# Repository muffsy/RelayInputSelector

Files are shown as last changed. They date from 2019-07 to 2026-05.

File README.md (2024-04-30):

# Muffsy Relay Input Selector 4

This open source (BSD license) project contains Arduino Code, Autodesk Eagle PCB project files and gerbers that can be sent directly to any PCB manufacturer for production.

- https://www.muffsy.com/muffsy-relay-input-selector-4.html
- https://www.tindie.com/products/skrodahl/muffsy-relay-input-selector-kit/

The Muffsy Relay Input Selector is a simple, reliable, high quality, DIY stereo input selector that's controlled by an ESP-32 and is slightly larger than a Post-IT note. 

The Input Selector has four inputs, one output, a mute circuit and the option of controlling a solid state relay. It's controlled with a rotary encoder and an IR remote. 

As the heart of the Input Selector is an ESP32, with all pins broken out on the board, the possibilities are virtually limitles. The example code is written in Arduino, the native SDK could of course be used instead.

This kit is meant to be paired with a preamplifier circuit, such as the Muffsy BSTRD Class-A Tube Preamp, Pass Labs B1 and many others.

**This project**, including the schematic and board layout, **is open source**. It's licensed under the very permissive BSD 3-Clause "New" or "Revised" License.

**Update 2023-07-30:**
The software now works without modifications of Arduino libraries.

**Update 2023-09-16:**
Much improved code, with user configurable values. In particular for the IR remote codes and rotary encoder direction.

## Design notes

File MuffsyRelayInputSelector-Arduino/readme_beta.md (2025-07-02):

# Muffsy Relay Input Selector - Enhanced Version (Beta)

🎵 **Version 2.0.0** - Now with WiFi control, web interface, and OTA updates!

## 🆕 What's New in Version 2.0

This enhanced version of the Muffsy Relay Input Selector adds modern connectivity features while maintaining all the original functionality you know and love.

### ✨ New Features

- **📱 WiFi Control** - Control your input selector from your phone, tablet, or computer
- **🌐 Web Interface** - Clean, responsive web interface for easy control
- **🔄 Over-The-Air Updates** - Update firmware wirelessly without cables
- **💻 Web Console** - View device logs and status remotely
- **🔧 Easy WiFi Setup** - Captive portal setup for connecting to your home network
- **💾 Enhanced Settings** - Automatic saving of all settings including WiFi credentials

### 🔒 Safety Improvements

- **Power-On Safety** - Device starts completely OFF and MUTED for maximum safety
- **Relay Protection** - All input relays turn off when muted or powered off
- **Startup Delay** - Configurable mute period during startup to protect amplifiers

---

## 🚀 Quick Start Guide

### 1. First Power-On

When you first power on your enhanced Muffsy Input Selector:

1. **Look for the WiFi network** `MuffsyInputSelector` on your phone/computer
2. **Connect using password**: `muffsy123`
3. **Open any website** - you'll be automatically redirected to the control interface
4. **Device starts OFF and MUTED** for safety - use Power button to turn on

### 2. Connect to Your Home WiFi

1. On the control interface, find the **WiFi Setup** section
2. **Enter your home WiFi** network name and password
3. **Click Connect** - the device will restart and connect to your network
4. **Find the IP address** in your router's connected devices, or check the Serial monitor

### 3. Bookmark the Control Interface

Once connected to your home WiFi:
- **Access via IP address**: `http://192.168.1.xxx` (your device's IP)
- **Bookmark this page** for easy access
- **Works on phones, tablets, and computers**

---

## 🎛️ Control Interface

### Main Control Page

Web Interface

The web interface provides:

#### 📊 Status Display
- **Power Status**: ON/OFF
- **Current Input**: Input 1-4
- **Mute Status**: YES/NO
- **WiFi Status**: Connected/Not Connected

#### 🎚️ Control Buttons
- **Power**: Turn the input selector on/off
- **Mute**: Mute/unmute audio output
- **Input 1-4**: Direct input selection buttons

#### ⚙️ Additional Features
- **Console**: View live device logs and status messages
- **Firmware Update**: Upload new firmware files
- **WiFi Setup**: Change WiFi network (if in AP mode)

---

## 💻 Web Console

### Accessing the Console

1. **Click "Open Console"** on the main interface
2. **New window opens** with live console output
3. **Watch real-time activity** as you use the device

### Console Features

- **🕒 Timestamped logs** - See exactly when events occurred
- **🔄 Auto-refresh** - Updates every 2 seconds automatically
- **📜 Scrolling history** - View up to 50 recent log entries
- **🧹 Clear function** - Reset console display
- **📱 Mobile friendly** - Works great on phones

### What You'll See

```
[0:02:15] Muffsy Relay Input Selector - Enhanced v2.0.0
[0:02:15] Hardware initialized
[0:02:16] Connected to WiFi!
[0:02:16] IP address: 192.168.1.100
[0:02:16] Setup complete - ready for operation
[0:02:45] IR received: 0x24
[0:02:45] Input selected: 2
[0:02:52] Power: OFF
[0:02:58] Power: ON
```

---

## 🔄 Firmware Updates

### Two Ways to Update

#### 1. Web Interface Upload (Recommended)
1. **Get the new firmware** (.bin file) from the releases page
2. **Go to Firmware Update** section on web interface
3. **Choose file** and click "Upload Firmware"
4. **Device updates automatically** and restarts

#### 2. Arduino IDE OTA (For Developers)
1. **Open Arduino IDE**
2. **Go to Tools → Port**
3. **Select "muffsy-input-selector" network port**
4. **Upload normally** - no USB cable needed!

### Creating Firmware Files
If you're compiling your own firmware:
1. **Arduino IDE**: Sketch → Export Compiled Binary
2. **Look for** `YourSketch.ino.esp32.bin` file
3. **Upload this file** via web interface

---

## 🎮 Control Methods

Your input selector responds to **three control methods**:

### 1. 📱 Web Interface
- **Power, Mute, Input selection**
- **Real-time status updates**
- **Works from anywhere on your network**

### 2. 📺 IR Remote Control
**Same IR codes as original version:**
- **Power**: 0x45
- **Mute**: 0x47  
- **Input 1**: 0x12
- **Input 2**: 0x24
- **Input 3**: 0x94
- **Input 4**: 0x8
- **Up/Down**: 0x18/0x52

### 3. 🎛️ Rotary Encoder
- **Rotate**: Change input (1→2→3→4→1...)
- **Short Press**: Power on/off
- **Long Press**: Mute/unmute

---

## ⚙️ Settings & Configuration

### Automatically Saved Settings
- **Current input selection** (survives power cycles)
- **WiFi network credentials**
- **SSR (Solid State Relay) enable/disable**

### User Configurable Options
Edit these in the source code before compiling:

```cpp
// WiFi Access Point settings
#define AP_SSID          "MuffsyInputSelector"
#define AP_PASSWORD      "muffsy123"

// Timing settings
#define STARTUP_DELAY    2000    // Startup mute delay (ms)
#define DEBOUNCE_DELAY   200     // Button debounce (ms)

// IR Remote codes (replace with your remote)
#define IR_POWER         0x45
#define IR_INPUT_1       0x12
// ... etc
```

---

## 🔧 Technical Details

### Hardware Compatibility
- **✅ Same PCB** - Works with existing Muffsy Input Selector hardware
- **✅ Same pins** - No hardware changes required
- **✅ Same relays** - All original relay functionality preserved
- **✅ Same components** - ESP32, rotary encoder, IR receiver

### Pin Configuration
| Function | ESP32 Pin | Notes |
|---|---|---|
| Input A Relay | 16 | Same as original |
| Input B Relay | 12 | Same as original |
| Input C Relay | 27 | Same as original |
| Input D Relay | 33 | Same as original |
| Mute Relay | 32 | Same as original |
| SSR Control | 17 | Same as original |
| Power LED | 2 | Same as original |
| Encoder CLK | 35 | Same as original |
| Encoder DT | 34 | Same as original |
| Encoder SW | 5 | Same as original |
| IR Receiver | 36 | Same as original |

### Network Information
- **Access Point Mode**: `MuffsyInputSelector` / `muffsy123`
- **Station Mode**: Connects to your home WiFi
- **Web Server**: Port 80 (standard HTTP)
- **OTA**: Password `muffsy`, hostname `muffsy-input-selector`

---

## 🛠️ Installation

### Required Libraries
Install these libraries in Arduino IDE:

1. **IRremote** by shirriff
2. **Versatile_RotaryEncoder** by Rui Seixas

ESP32 core libraries (included automatically):
- WiFi, WebServer, ArduinoOTA, Preferences, DNSServer

### Compilation & Upload
1. **Select board**: NodeMCU-32S
2. **Select port**: Your ESP32's USB port
3. **Compile and upload** normally
4. **Device creates WiFi AP** on first boot

---

## 🚨 Safety Features

### Startup Safety Sequence
1. **All relays OFF** immediately on power-up
2. **Device starts POWERED OFF**
3. **Device starts MUTED**
4. **Startup delay period** (configurable, default 2 seconds)
5. **User must explicitly turn on** via any control method

### Operational Safety
- **Mute activates** when powering off
- **All input relays turn off** when muted
- **SSR control** follows power state
- **Settings auto-save** to prevent loss

---

## 🆘 Troubleshooting

### WiFi Connection Issues

**Problem**: Can't connect to home WiFi
**Solution**: 
1. Hold down reset button for 10+ seconds to factory reset WiFi settings
2. Device will restart in Access Point mode
3. Reconnect and re-enter WiFi credentials

**Problem**: Can't find device IP address
**Solution**:
1. Check your router's connected devices list
2. Look for "muffsy-input-selector" or similar
3. Use Serial monitor to see IP address during startup

### Web Interface Issues

**Problem**: Web interface won't load
**Solution**:
1. Check device is connected to WiFi (LED indicators)
2. Try refreshing browser page
3. Clear browser cache
4. Try different browser/device

**Problem**: Controls don't work
**Solution**:
1. Check device power status
2. Refresh web page
3. Check console for error messages

### Hardware Issues

**Problem**: IR remote not working
**Solution**:
1. Check console for "IR received" messages
2. Point remote directly at IR receiver
3. Replace remote batteries
4. Verify IR codes in source code match your remote

**Problem**: Rotary encoder not working
**Solution**:
1. Check encoder connections
2. Try different rotation speeds
3. Check console for encoder activity
4. Verify pin assignments

### OTA Update Issues

**Problem**: OTA update fails
**Solution**:
1. Ensure device and computer on same network
2. Check Arduino IDE has ESP32 OTA port available
3. Try web interface update instead
4. Restart device and try again

---

## 📞 Support & More Information

### Original Project
- **Website**: [muffsy.com](https://www.muffsy.com/muffsy-relay-input-selector-4)
- **GitHub**: [github.com/muffsy/RelayInputSelector](https://github.com/muffsy/RelayInputSelector)
- **Tindie Store**: [Available as kit](https://www.tindie.com/products/skrodahl/muffsy-relay-input-selector-kit/)

### Enhanced Version
- **This is a community enhancement** of the original open-source project
- **All new features** maintain compatibility with original hardware
- **Open source** under same BSD 3-Clause license

### Getting Help
1. **Check console** for error messages
2. **Try Serial monitor** for detailed debugging  
3. **Reset to factory defaults** if needed
4. **Community support** via original project channels

---

## 🎉 Enjoy Your Enhanced Input Selector!

Your Muffsy Relay Input Selector now has modern connectivity while maintaining the same high-quality audio switching you expect. Control it from anywhere in your home, update firmware wirelessly, and monitor its operation through the web console.

**Happy listening! 🎵**

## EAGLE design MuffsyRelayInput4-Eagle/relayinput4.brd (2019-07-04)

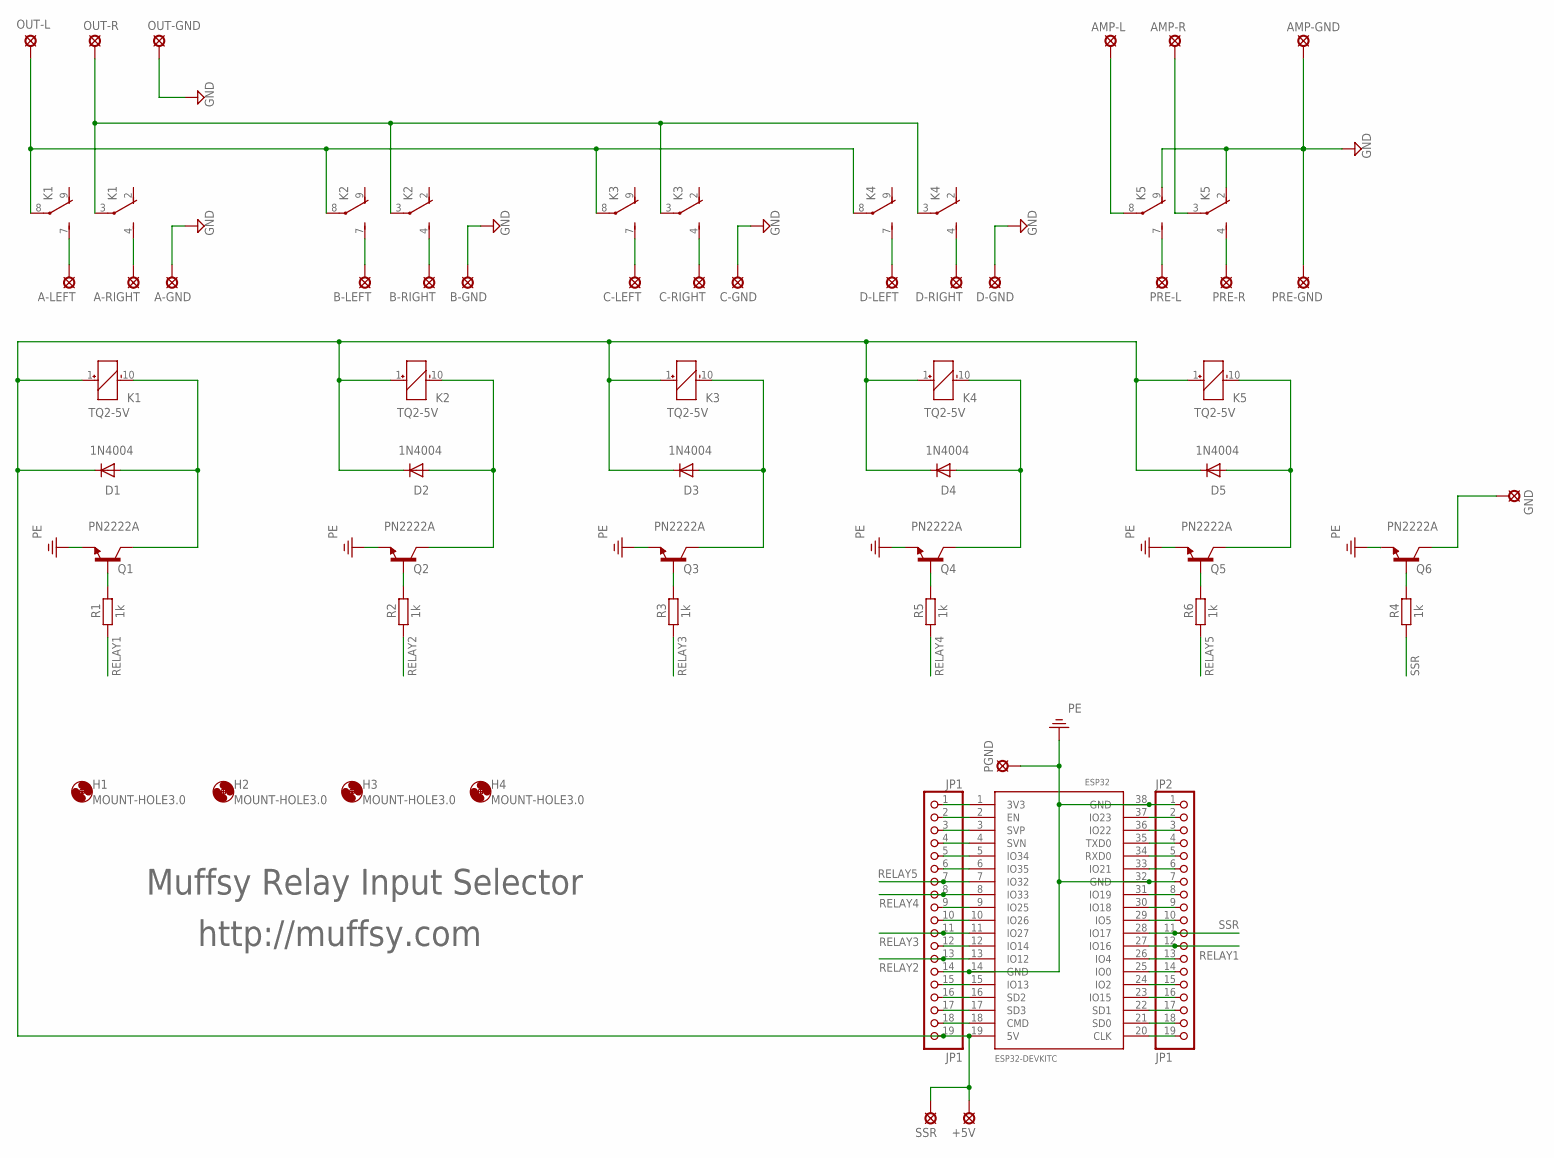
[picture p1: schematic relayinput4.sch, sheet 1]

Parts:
+5V: SE11
A-GND: SE11
A-LEFT: SE11
A-RIGHT: SE11
AMP-GND: SE11
AMP-L: SE11
AMP-R: SE11
B-GND: SE11
B-LEFT: SE11
B-RIGHT: SE11
C-GND: SE11
C-LEFT: SE11
C-RIGHT: SE11
D1, D2, D3, D4, D5: 1N4004; DO41-10
D-GND: SE11
D-LEFT: SE11
D-RIGHT: SE11
ESP32: ESP32DEVKITC; ESP32-DEVKITC
GND: SE11
H1, H2, H3, H4: MOUNT-HOLE3.0; 3,0
JP1, JP2: JP1; 1X19
K1, K2, K3, K4, K5: TQ2-5V; TQ2
OUT-GND: SE11
OUT-L: SE11
OUT-R: SE11
PGND: SE11
PRE-GND: SE11
PRE-L: SE11
PRE-R: SE11
Q1, Q2, Q3, Q4, Q5, Q6: PN2222A; TO92
R1, R2, R3, R4, R5, R6: 1k; 0207/10
SSR: SE11

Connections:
GND: A-GND.MP, AMP-GND.MP, B-GND.MP, C-GND.MP, D-GND.MP, K5.2 (O), K5.9 (O), OUT-GND.MP, PRE-GND.MP
unnamed: B-LEFT.MP, K2.7 (S)
unnamed: A-LEFT.MP, K1.7 (S)
unnamed: A-RIGHT.MP, K1.4 (S)
unnamed: B-RIGHT.MP, K2.4 (S)
unnamed: C-LEFT.MP, K3.7 (S)
unnamed: C-RIGHT.MP, K3.4 (S)
unnamed: D-LEFT.MP, K4.7 (S)
unnamed: D-RIGHT.MP, K4.4 (S)
unnamed: K5.7 (S), PRE-L.MP
unnamed: K5.4 (S), PRE-R.MP
unnamed: Q1.B, R1.2
unnamed: K1.3, K2.3, K3.3, K4.3, OUT-R.MP
unnamed: K1.8, K2.8, K3.8, K4.8, OUT-L.MP
unnamed: Q2.B, R2.2
unnamed: +5V.MP, D1.C, D2.C, D3.C, D4.C, D5.C, ESP32.19 (5V), JP1.19, K1.1 (+), K2.1 (+), K3.1 (+), K4.1 (+), K5.1 (+), SSR.MP
unnamed: Q3.B, R3.2
unnamed: Q4.B, R5.2
unnamed: Q5.B, R6.2
unnamed: ESP32.1 (3V3), JP1.1
unnamed: D1.A, K1.10 (-), Q1.C
unnamed: D2.A, K2.10 (-), Q2.C
unnamed: D3.A, K3.10 (-), Q3.C
unnamed: D4.A, K4.10 (-), Q4.C
unnamed: D5.A, K5.10 (-), Q5.C
unnamed: ESP32.2 (EN), JP1.2
unnamed: ESP32.3 (SVP), JP1.3
unnamed: ESP32.4 (SVN), JP1.4
unnamed: ESP32.5 (IO34), JP1.5
unnamed: ESP32.6 (IO35), JP1.6
unnamed: AMP-R.MP, K5.3
unnamed: AMP-L.MP, K5.8
unnamed: ESP32.10 (IO26), JP1.10
unnamed: ESP32.12 (IO14), JP1.12
unnamed: ESP32.9 (IO25), JP1.9
unnamed: GND.MP, Q6.C
unnamed: ESP32.15 (IO13), JP1.15
unnamed: Q6.B, R4.2
unnamed: ESP32.29 (IO5), JP2.10
unnamed: ESP32.36 (IO22), JP2.3
unnamed: ESP32.16 (SD2), JP1.16
unnamed: ESP32.17 (SD3), JP1.17
unnamed: ESP32.18 (CMD), JP1.18
unnamed: ESP32.37 (IO23), JP2.2
unnamed: ESP32.35 (TXD0), JP2.4
unnamed: ESP32.34 (RXD0), JP2.5
unnamed: ESP32.33 (IO21), JP2.6
unnamed: ESP32.31 (IO19), JP2.8
unnamed: ESP32.30 (IO18), JP2.9
unnamed: ESP32.26 (IO4), JP2.13
unnamed: ESP32.25 (IO0), JP2.14
unnamed: ESP32.24 (IO2), JP2.15
unnamed: ESP32.23 (IO15), JP2.16
unnamed: ESP32.22 (SD1), JP2.17
unnamed: ESP32.21 (SD0), JP2.18
unnamed: ESP32.20 (CLK), JP2.19
PE: ESP32.14 (GND), ESP32.32 (GND), ESP32.38 (GND), JP1.14, JP2.1, JP2.7, PGND.MP, Q1.E, Q2.E, Q3.E, Q4.E, Q5.E, Q6.E
RELAY1: ESP32.27 (IO16), JP2.12, R1.1
RELAY2: ESP32.13 (IO12), JP1.13, R2.1
RELAY3: ESP32.11 (IO27), JP1.11, R3.1
RELAY4: ESP32.8 (IO33), JP1.8, R5.1
RELAY5: ESP32.7 (IO32), JP1.7, R6.1
SSR: ESP32.28 (IO17), JP2.11, R4.1

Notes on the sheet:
Muffsy Relay Input Selector
http://muffsy.com

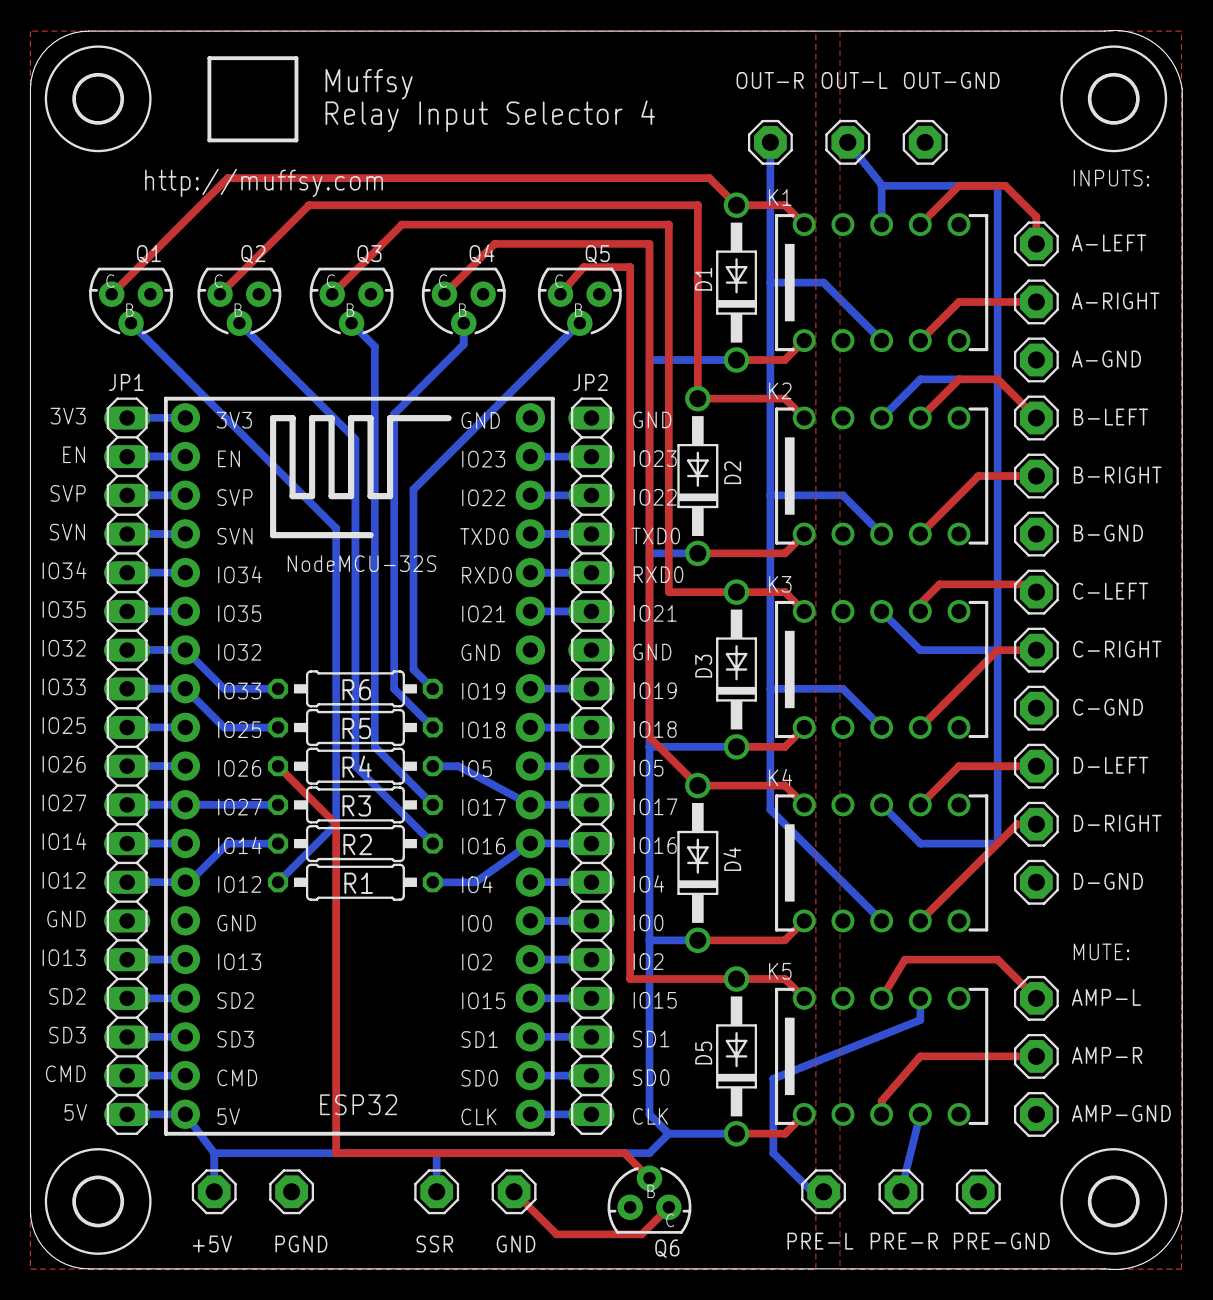
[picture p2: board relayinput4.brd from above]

Board: 2 copper layers, 75.6 x 81.3 mm, 54 parts (0 on the bottom side), 63 nets.

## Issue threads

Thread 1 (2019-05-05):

IRrecvDemo:23:21: error: no matching function for call to 'IRrecv::enableIRIn()'

RudyFiero, 2019-05-05:
I got the above error when I tried to compile the IRrecvDemo. I copied the IRremote directory to my library directory. I restarted the Arduino program. I loaded the example through File>Examples>IRremote.

It looks like the files are being included.

`Using library IRremote at version 2.2.3 in folder: C:\Users\wrpa\Documents\Arduino\libraries\IRremote `

From the following.

```
Arduino: 1.8.8 (Windows 10), Board: "ESP32 Dev Module, Disabled, Default, 240MHz (WiFi/BT), QIO, 80MHz, 4MB (32Mb), 921600, Verbose"

C:\Program Files (x86)\Arduino\arduino-builder -dump-prefs -logger=machine -hardware C:\Program Files (x86)\Arduino\hardware -hardware C:\Users\wrpa\AppData\Local\Arduino15\packages -hardware C:\Users\wrpa\Documents\Arduino\hardware -tools C:\Program Files (x86)\Arduino\tools-builder -tools C:\Program Files (x86)\Arduino\hardware\tools\avr -tools C:\Users\wrpa\AppData\Local\Arduino15\packages -built-in-libraries C:\Program Files (x86)\Arduino\libraries -libraries C:\Users\wrpa\Documents\Arduino\libraries -fqbn=espressif:esp32:esp32:PSRAM=disabled,PartitionScheme=default,CPUFreq=240,FlashMode=qio,FlashFreq=80,FlashSize=4M,UploadSpeed=921600,DebugLevel=verbose -ide-version=10808 -build-path C:\Users\wrpa\AppData\Local\Temp\arduino_build_774911 -warnings=none -build-cache C:\Users\wrpa\AppData\Local\Temp\arduino_cache_269349 -prefs=build.warn_data_percentage=75 -verbose C:\Users\wrpa\Documents\Arduino\libraries\IRremote\examples\IRrecvDemo\IRrecvDemo.ino
C:\Program Files (x86)\Arduino\arduino-builder -compile -logger=machine -hardware C:\Program Files (x86)\Arduino\hardware -hardware C:\Users\wrpa\AppData\Local\Arduino15\packages -hardware C:\Users\wrpa\Documents\Arduino\hardware -tools C:\Program Files (x86)\Arduino\tools-builder -tools C:\Program Files (x86)\Arduino\hardware\tools\avr -tools C:\Users\wrpa\AppData\Local\Arduino15\packages -built-in-libraries C:\Program Files (x86)\Arduino\libraries -libraries C:\Users\wrpa\Documents\Arduino\libraries -fqbn=espressif:esp32:esp32:PSRAM=disabled,PartitionScheme=default,CPUFreq=240,FlashMode=qio,FlashFreq=80,FlashSize=4M,UploadSpeed=921600,DebugLevel=verbose -ide-version=10808 -build-path C:\Users\wrpa\AppData\Local\Temp\arduino_build_774911 -warnings=none -build-cache C:\Users\wrpa\AppData\Local\Temp\arduino_cache_269349 -prefs=build.warn_data_percentage=75 -verbose C:\Users\wrpa\Documents\Arduino\libraries\IRremote\examples\IRrecvDemo\IRrecvDemo.ino
Using board 'esp32' from platform in folder: C:\Users\wrpa\Documents\Arduino\hardware\espressif\esp32
Using core 'esp32' from platform in folder: C:\Users\wrpa\Documents\Arduino\hardware\espressif\esp32
Detecting libraries used...
"C:\\Users\\wrpa\\Documents\\Arduino\\hardware\\espressif\\esp32/tools/xtensa-esp32-elf/bin/xtensa-esp32-elf-g++" -DESP_PLATFORM "-DMBEDTLS_CONFIG_FILE=\"mbedtls/esp_config.h\"" -DHAVE_CONFIG_H "-IC:\\Users\\wrpa\\Documents\\Arduino\\hardware\\espressif\\esp32/tools/sdk/include/config" "-IC:\\Users\\wrpa\\Documents\\Arduino\\hardware\\espressif\\esp32/tools/sdk/include/app_trace" "-IC:\\Users\\wrpa\\Documents\\Arduino\\hardware\\espressif\\esp32/tools/sdk/include/app_update" "-IC:\\Users\\wrpa\\Documents\\Arduino\\hardware\\espressif\\esp32/tools/sdk/include/asio" "-IC:\\Users\\wrpa\\Documents\\Arduino\\hardware\\espressif\\esp32/tools/sdk/include/bootloader_support" "-IC:\\Users\\wrpa\\Documents\\Arduino\\hardware\\espressif\\esp32/tools/sdk/include/bt" "-IC:\\Users\\wrpa\\Documents\\Arduino\\hardware\\espressif\\esp32/tools/sdk/include/coap" "-IC:\\Users\\wrpa\\Documents\\Arduino\\hardware\\espressif\\esp32/tools/sdk/include/console" "-IC:\\Users\\wrpa\\Documents\\Arduino\\hardware\\espressif\\esp32/tools/sdk/include/driver" "-IC:\\Users\\wrpa\\Documents\\Arduino\\hardware\\espressif\\esp32/tools/sdk/include/esp-tls" "-IC:\\Users\\wrpa\\Documents\\Arduino\\hardware\\espressif\\esp32/tools/sdk/include/esp32" "-IC:\\Users\\wrpa\\Documents\\Arduino\\hardware\\espressif\\esp32/tools/sdk/include/esp_adc_cal" "-IC:\\Users\\wrpa\\Documents\\Arduino\\hardware\\espressif\\esp32/tools/sdk/include/esp_event" "-IC:\\Users\\wrpa\\Documents\\Arduino\\hardware\\espressif\\esp32/tools/sdk/include/esp_http_client" "-IC:\\Users\\wrpa\\Documents\\Arduino\\hardware\\espressif\\esp32/tools/sdk/include/esp_http_server" "-IC:\\Users\\wrpa\\Documents\\Arduino\\hardware\\espressif\\esp32/tools/sdk/include/esp_https_ota" "-IC:\\Users\\wrpa\\Documents\\Arduino\\hardware\\espressif\\esp32/tools/sdk/include/esp_https_server" "-IC:\\Users\\wrpa\\Documents\\Arduino\\hardware\\espressif\\esp32/tools/sdk/include/esp_ringbuf" "-IC:\\Users\\wrpa\\Documents\\Arduino\\hardware\\espressif\\esp32/tools/sdk/include/ethernet" "-IC:\\Users\\wrpa\\Documents\\Arduino\\hardware\\espressif\\esp32/tools/sdk/include/expat" "-IC:\\Users\\wrpa\\Documents\\Arduino\\hardware\\espressif\\esp32/tools/sdk/include/fatfs" "-IC:\\Users\\wrpa\\Documents\\Arduino\\hardware\\espressif\\esp32/tools/sdk/include/freemodbus" "-IC:\\Users\\wrpa\\Documents\\Arduino\\hardware\\espressif\\esp32/tools/sdk/include/freertos" "-IC:\\Users\\wrpa\\Documents\\Arduino\\hardware\\espressif\\esp32/tools/sdk/include/heap" "-IC:\\Users\\wrpa\\Documents\\Arduino\\hardware\\espressif\\esp32/tools/sdk/include/idf_test" "-IC:\\Users\\wrpa\\Documents\\Arduino\\hardware\\espressif\\esp32/tools/sdk/include/jsmn" "-IC:\\Users\\wrpa\\Documents\\Arduino\\hardware\\espressif\\esp32/tools/sdk/include/json" "-IC:\\Users\\wrpa\\Documents\\Arduino\\hardware\\espressif\\esp32/tools/sdk/include/libsodium" "-IC:\\Users\\wrpa\\Documents\\Arduino\\hardware\\espressif\\esp32/tools/sdk/include/log" "-IC:\\Users\\wrpa\\Documents\\Arduino\\hardware\\espressif\\esp32/tools/sdk/include/lwip" "-IC:\\Users\\wrpa\\Documents\\Arduino\\hardware\\espressif\\esp32/tools/sdk/include/mbedtls" "-IC:\\Users\\wrpa\\Documents\\Arduino\\hardware\\espressif\\esp32/tools/sdk/include/mdns" "-IC:\\Users\\wrpa\\Documents\\Arduino\\hardware\\espressif\\esp32/tools/sdk/include/micro-ecc" "-IC:\\Users\\wrpa\\Documents\\Arduino\\hardware\\espressif\\esp32/tools/sdk/include/mqtt" "-IC:\\Users\\wrpa\\Documents\\Arduino\\hardware\\espressif\\esp32/tools/sdk/include/newlib" "-IC:\\Users\\wrpa\\Documents\\Arduino\\hardware\\espressif\\esp32/tools/sdk/include/nghttp" "-IC:\\Users\\wrpa\\Documents\\Arduino\\hardware\\espressif\\esp32/tools/sdk/include/nvs_flash" "-IC:\\Users\\wrpa\\Documents\\Arduino\\hardware\\espressif\\esp32/tools/sdk/include/openssl" "-IC:\\Users\\wrpa\\Documents\\Arduino\\hardware\\espressif\\esp32/tools/sdk/include/protobuf-c" "-IC:\\Users\\wrpa\\Documents\\Arduino\\hardware\\espressif\\esp32/tools/sdk/include/protocomm" "-IC:\\Users\\wrpa\\Documents\\Arduino\\hardware\\espressif\\esp32/tools/sdk/include/pthread" "-IC:\\Users\\wrpa\\Documents\\Arduino\\hardware\\espressif\\esp32/tools/sdk/include/sdmmc" "-IC:\\Users\\wrpa\\Documents\\Arduino\\hardware\\espressif\\esp32/tools/sdk/include/smartconfig_ack" "-IC:\\Users\\wrpa\\Documents\\Arduino\\hardware\\espressif\\esp32/tools/sdk/include/soc" "-IC:\\Users\\wrpa\\Documents\\Arduino\\hardware\\espressif\\esp32/tools/sdk/include/spi_flash" "-IC:\\Users\\wrpa\\Documents\\Arduino\\hardware\\espressif\\esp32/tools/sdk/include/spiffs" "-IC:\\Users\\wrpa\\Documents\\Arduino\\hardware\\espressif\\esp32/tools/sdk/include/tcp_transport" "-IC:\\Users\\wrpa\\Documents\\Arduino\\hardware\\espressif\\esp32/tools/sdk/include/tcpip_adapter" "-IC:\\Users\\wrpa\\Documents\\Arduino\\hardware\\espressif\\esp32/tools/sdk/include/ulp" "-IC:\\Users\\wrpa\\Documents\\Arduino\\hardware\\espressif\\esp32/tools/sdk/include/unity" "-IC:\\Users\\wrpa\\Documents\\Arduino\\hardware\\espressif\\esp32/tools/sdk/include/vfs" "-IC:\\Users\\wrpa\\Documents\\Arduino\\hardware\\espressif\\esp32/tools/sdk/include/wear_levelling" "-IC:\\Users\\wrpa\\Documents\\Arduino\\hardware\\espressif\\esp32/tools/sdk/include/wifi_provisioning" "-IC:\\Users\\wrpa\\Documents\\Arduino\\hardware\\espressif\\esp32/tools/sdk/include/wpa_supplicant" "-IC:\\Users\\wrpa\\Documents\\Arduino\\hardware\\espressif\\esp32/tools/sdk/include/xtensa-debug-module" "-IC:\\Users\\wrpa\\Documents\\Arduino\\hardware\\espressif\\esp32/tools/sdk/include/esp32-camera" "-IC:\\Users\\wrpa\\Documents\\Arduino\\hardware\\espressif\\esp32/tools/sdk/include/esp-face" "-IC:\\Users\\wrpa\\Documents\\Arduino\\hardware\\espressif\\esp32/tools/sdk/include/fb_gfx" -std=gnu++11 -fno-exceptions -Os -g3 -Wpointer-arith -fexceptions -fstack-protector -ffunction-sections -fdata-sections -fstrict-volatile-bitfields -mlongcalls -nostdlib -w -Wno-error=unused-function -Wno-error=unused-but-set-variable -Wno-error=unused-variable -Wno-error=deprecated-declarations -Wno-unused-parameter -Wno-sign-compare -fno-rtti -c -w -x c++ -E -CC -DF_CPU=240000000L -DARDUINO=10808 -DARDUINO_ESP32_DEV -DARDUINO_ARCH_ESP32 "-DARDUINO_BOARD=\"ESP32_DEV\"" "-DARDUINO_VARIANT=\"esp32\"" -DESP32 -DCORE_DEBUG_LEVEL=5 "-IC:\\Users\\wrpa\\Documents\\Arduino\\hardware\\espressif\\esp32\\cores\\esp32" "-IC:\\Users\\wrpa\\Documents\\Arduino\\hardware\\espressif\\esp32\\variants\\esp32" "C:\\Users\\wrpa\\AppData\\Local\\Temp\\arduino_build_774911\\sketch\\IRrecvDemo.ino.cpp" -o nul
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

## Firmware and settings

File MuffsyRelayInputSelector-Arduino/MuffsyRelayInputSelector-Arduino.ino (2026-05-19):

/* Muffsy Relay Input Selector
 *      
 * Control relays using IR and rotary encoder
 * Control external power to amp using IR and push button
 * http://muffsy.com
 *
 * Last update with functionality changes: 2023-09-27
 *
 * Introduction:
 * The software works on the concept of "powerState", which determines the behavior of the Input Selector:
 * 
 * 0: Boot
 *   Read last input channel from NVRAM, selecting the same input as when the input selector was turned off or lost power 
 *   The input selector is muted, and mute LED is turned off 
 *   Print startup message
 *   powerState is changed to 2 (off)
 *
   2: Power OFF
 *   Turn off all relays
 *   Set power amp to off (SSR = LOW)
 *   The input selector is muted, and mute LED is turned off
 *   Limited functionality, only IR powerbutton and rotary encoder pushbutton is active
 *   All input events, even those not available, will be shown in the serial monitor
 *        
 * 1: Power ON
 *   Turn on power button LED
 *   Set power amp to on, SSR = HIGH
 *   Activates the input channel read from NVRAM
 *   Will start muted with mute LED turned on
 *   No actions are read until the input selector unmutes after 1500 ms (default)
 *   All functions available, IR Remote and rotary encoder
 *   All input events and actions will be shown in the serial monitor
 */

/*
 * Load libraries
 */
#include <EEPROM.h> // EEPROM Library
#include <IRremote.h> // IR Remote Library
#include <Versatile_RotaryEncoder.h> // Rotary Encoder Library

/*
 * Startup delay
 *
 * When powering on, the input selector is muted to avoid any unwanted pops
 * Set the delay value in milliseconds (default 1500)
 *
 * Change to 0 for no delay
 */
#define startupDelay 1500

/*
 * Enable SSR
 *
 * If you want to use a Solid State Relay to control mains power to an
 * amplifier or similar, set this value to 1
 *
 * Default 0 (disabled), as handling mains power is dangerous
 */
 #define enableSSR 0

/*
 * Auto power on
 *
 * If set to 1, the input selector will power on automatically after the
 * welcome/getting ready message, without having to press the rotary
 * encoder pushbutton or the IR remote power button.
 *
 * Default 0 (disabled)
 */
 #define autoPowerOn 0

/* Mute and Power on / off:
 *
 * The rotary encoder is also a push button, which registers
 * either a short or a long press. These are their functions:
 *
 *    Short press: Power on / off
 *    Long press: Mute
 *
 * To reverse this behaviour, change the value below to 1 (default = 0)
 */
 #define encPush 0

/* 
 * Rotary encoder direction.
 *
 * If the rotary encoder rotation is the wrong way around, change this value to 1
 * Default: 0
 */
 #define encDirection 0

/* 
 * Rotational encoder rate
 *
 * Delay between registering rotational encoder turns, in milliseconds.
 * If the repeat rate when turning the rotational encoder is too fast, change this timer.
 *
 * Note:
 * Introducing a delay in reading turns of the rotational encoder may skip one or more
 * of the encoders "clicks". In turn, it prevents you from skipping channels if you turn
 * the encoder to fast.
 *
 * Lower number: Faster repeat rate
 * Higher number: Slower repeat rate
 * Default: 0
 */
#define rotRate 0

/* 
 * IR rate
 *
 * Delay between registering IR commands, in milliseconds.
 * If the repeat rate when holding down a button on the remote is
 * to slow or too fast, change this timer.
 *
 * Lower number: Faster repeat rate
 * Higher number: Slower repeat rate
 * Default: 175
 */
#define irRate 175

/*
 *IR Commands
 *
 * The following variables map all the buttons on the remote
 * control that comes with the Muffsy Input Selector.
 *
 * For instructions on how to configure your own remote, see:
 * https://www.muffsy.com/muffsy-relay-input-selector-4#configureremote
 *
 * While connecting your Input Selector to the computer, it will display
 * any remote commands in the Arduiono IDE's Serial Monitor like this:
 *
 *    [http://muffsy.com]: Received IR code: <IR code of button pushed>
 *
 * There are placeholder commands in the function irRemote{} for the buttons
 * 0 and 5 to 9 that serves as templates for your own IR routines
 *
 */
#define zeroButton 13       // Placeholder command in the function irRemote{}, default: 13
#define oneButton 12        // Input 1, default: 12
#define twoButton 24        // Input 2, default: 24
#define threeButton 94      // Input 3, default: 94
#define fourButton 8        // Input 4, default: 8
#define fiveButton 28       // Placeholder command in the function irRemote{}, default: 28
#define sixButton 90        // Placeholder command in the function irRemote{}, default: 90
#define sevenButton 66      // Placeholder command in the function irRemote{}, default: 66
#define eightButton 82      // Placeholder command in the function irRemote{}, default: 82
#define nineButton 74       // Placeholder command in the function irRemote{}, default: 74
#define eqButton 70         // Default value: 70
#define modeButton 68       // Default value: 68
#define muteButton 71       // Mute, default: 71
#define ffButton 21         // "Fast Forward" button: Channel up, default: 21
#define rewButton 7         // "Rewind" button: Channel down, default: 7
#define powerButton 69      // Power on / off, default: 69
#define volupButton 25      // Default value: 25
#define voldownButton 22    // Default value: 22
#define rptButton 64        // Default value: 64
#define tfuButton 67        // Default value: 67
#define playButton 9        // Default value: 9

/**********************************************************
 * Do not edit below, unless you intend to change the code!
 **********************************************************/

// Rotary encoder pins
#define clk 35  // (A3)
#define dt 34   // (A4)
#define sw 5   // (A5)

// Functions prototyping to be handled on each Encoder Event
void handleRotate(int8_t rotation);
void handlePressRelease();
void handleLongPress();

// Create a global pointer for the encoder object
Versatile_RotaryEncoder *versatile_encoder;

//  EEPROM size: 1 (relayCount)
#define EEPROM_SIZE 1
// Variables, pin definitions

// Onboard LED/Power LED
#define LED 2

// IR Receiver pin and setup
//const byte IR_Recv = 36;
#define IR_Recv 36

// Relays
#define R1 16
#define R2 12
#define R3 27
#define R4 33
#define R5 32

//Solid State Relay
#define SSR 17

// Mute LED
#define muteLed 4

// Relay Array
volatile int relays[] = {16, 12, 27, 33, 32};

// Relay variables
volatile int relayCount;
int previousRelay;
int relayNumber;

/*
 * Power/Mute variables
 *
 * powerState explained in detail at the beginning of this program:
 *  0 = Welcome message, getting ready
 *  1 = Powered on
 *  2 = Powered off
 *
 * mute:
 *  0: Tell toggleMute() to unmute
 *  1: Tell toggleMute() to mute
 *
 * poweronMute:
 *  1: mute for the period defined by startupDelay, then unmute, only when powering on (change powerState to 1)
 *  0: Disable the startupDelay if powerState is unchanged
 */
int powerState = 0;   // Power ready-state
int mute = 1;         // Mute off/on (0/1) -> The circuit starts out muted, tell toggleMute() to stay muted at first run
int poweronMute = 1;  // Mute at poweron, with startupDelay

void setup() {

  Serial.begin(115200); // Set serial monitor transfer rate to 115,200
	versatile_encoder = new Versatile_RotaryEncoder(clk, dt, sw);

  // Load to the rotary encoder functions
  versatile_encoder->setHandleRotate(handleRotate);
  versatile_encoder->setHandlePressRelease(handlePressRelease);
  versatile_encoder->setHandleLongPress(handleLongPress);
  // Modify rotary encoder defualt values (optional)
  versatile_encoder->setReadIntervalDuration(3);    // set 3 ms as long press duration (default is 1 ms)
  // versatile_encoder->setShortPressDuration(35);  // set 35 ms as short press duration (default is 50 ms)
  // versatile_encoder->setLongPressDuration(550);  // set 550 ms as long press duration (default is 1000 ms)

  // Define INPUT pins, make sure the inputs aren't touch enabled
  pinMode (sw,INPUT_PULLUP);
  pinMode (clk,INPUT_PULLDOWN);
  pinMode (dt,INPUT_PULLDOWN);
  pinMode (IR_Recv,INPUT_PULLUP);

  // Define OUTPUT pins
  // Onboard LED
  pinMode (LED,OUTPUT);

  // Mute LED
  pinMode (muteLed,OUTPUT);

  // Relays
  pinMode (R1,OUTPUT);
  pinMode (R2,OUTPUT);
  pinMode (R3,OUTPUT);
  pinMode (R4,OUTPUT);
  pinMode (R5,OUTPUT);
  pinMode (SSR,OUTPUT);

  // Relay variables
  EEPROM.begin(EEPROM_SIZE);
  relayCount = EEPROM.read(0);
  previousRelay = relayCount + 1; // Start out not matching relayCount

  // Enable IR Receiver
  IrReceiver.begin(IR_Recv);
}

/******
 * Main loop
 ******/

void loop() {
  if (powerState == 0) { // Booting, welcome message
    powerOn();

  } else if (powerState == 1){ // Powered on
      relayOn();    // Will automatically change input if a function changes the relayCount variable
      irRemote();   // Allowing all functionality in the irRemote() function
      rotEncoder(); // Read the rotaryencoder 

  } else { // Powered off
      irRemote();   // irRemote() function, react to Power on/off only
      rotEncoder(); // Read the rotaryencoder, react to Power on/off only
  }

} // End Main loop

/******
 * Functions
 ******/

/*
 * Power on amplifier (Welcome/Boot message when first powered on)
 */
void powerOn() { // Only called if powerState is 0 (Ready-status)
  Serial.println("\n       --- http://muffsy.com ---\n");
  Serial.println("The Muffsy Relay Input Selector has woken up!\n");
  Serial.print(" ** Reading saved relay state from NVRAM: ");
  Serial.println(relayCount);
  digitalWrite(relays[4],LOW);

  Serial.println("\n ** Mute Relay turned ON");
  Serial.println(" ** All input relays are turned OFF");
  relayOff();

  Serial.println(" ** Solid State Relay is turned OFF\n");
  digitalWrite (SSR,LOW);
  Serial.println(" ** Startup completed - waiting for Power ON\n");
  Serial.println("       -------------------------\n");

  // Set powerState to 2 (Powered off). This function will not run again.
  powerState = 2;

  // If autoPowerOn is enabled, power on immediately after the welcome message
  if (autoPowerOn == 1) {
    Serial.println("[http://muffsy.com]: Auto power on enabled\n");
    togglePower();
  }
} // End powerOn()

 /*
  * Turn off all relays
  */
void relayOff() {
    for (int off = 0; off <= 3; off++) {
    digitalWrite(relays[off], LOW);
  } 
} // End relayOff


 /*
  * Turn on or off input relays (mute relay is controlled by toggleMute())
  *
  * relayCount is the actual chosen active relay
  * previousRelay is the previous chosen active relay
  * This function is triggered if the two are unequal
  * The function can be forced to trigger by changing previousRelay: previousRelay = relayCount + 1;
  */
void relayOn() {
  // If relayCount has changed: Turn on the selected relay (next, previous, direct)
  // If previousRelay has changed: Turn on the last selected relay
  if (relayCount != previousRelay) {
    auto localRelayCount = relayCount; // local copy, assuming atomic integer

    /* Rollover 3 or 0, 
     *
     * There are four input relays, 0 to 3 (Status messages prints them as inputs 1 to 4)
     * This part makes sure we can't choose relays lower than 0 or higher than 3
     */
    if (localRelayCount > 3) {
      localRelayCount = 0;
    } else if (localRelayCount < 0) {
      localRelayCount = 3;
    }

    // Turn off all relays, then turn on localRelayCount
    relayOff();
    digitalWrite(relays[localRelayCount], HIGH);
    relayCount = localRelayCount;

    // Write relayCount to memory
    EEPROM.write(0,relayCount);
    EEPROM.commit();
    Serial.print("[http://muffsy.com]: Written \"relayCount = ");
    Serial.print(relayCount);
    Serial.println("\" to save slot 0");
      
    // Reset counters, output relayNumber
    previousRelay = relayCount;
    relayNumber = relayCount + 1;
    Serial.print("[http://muffsy.com]: Activated relay #");
    Serial.println(relayNumber);
    Serial.println();

    /* 
     * Mute, then unmute if just powered on
     * relayOn() is called at power on, placing the startupDelay mute here is convenient so we don't have to run a separate function
     * If the configurable value startupMute is 0, there will be no delay
     */
    if ((poweronMute == 1) && (startupDelay == 0)) {
      poweronMute = 0; // Set poweronMute to 0, so this mutedelay doesn't occur every time the circuit is muted
      mute = 0; // toggleMute will unmute
      toggleMute;

    } else if (poweronMute == 1) {
      poweronMute = 0; // Set poweronMute to 0, so this mutedelay doesn't occur every time the circuit is muted
      Serial.println("[http://muffsy.com]: Turning on mute LED");
      digitalWrite(muteLed,HIGH);
      Serial.print("[http://muffsy.com]: Milliseconds delay before turning off mute: ");
      Serial.println(startupDelay);
      delay(startupDelay);
      mute = 0; // toggleMute will unmute when called next
      toggleMute();
    }
  }
} // End relayOn()

/*
 * Mute activate/deactivate
 */
void toggleMute() {
  // This function will mute if unmuted, and vice versa everytime it's called
  if (mute == 1) { // Read mute variable. if unmuted, turn on mute
    Serial.println("[http://muffsy.com]: Mute relay turned ON");
    digitalWrite(relays[4],LOW);

    if (powerState == 1){ // If powered on, also turn on mute LED
      Serial.println("[http://muffsy.com]: Turning on mute LED\n");
      digitalWrite(muteLed,HIGH);

      // Set mute to 0, next time toggleMute is called, it will turn OFF mute
      // mute = 0 now means we're muted
      mute = 0; // Unmute next time this function is called
    } // End if powered on

  } else { // Mute must be 0, turn off mute
    Serial.println("[http://muffsy.com]: Mute relay turned OFF");
    digitalWrite(relays[4],HIGH);
    Serial.println("[http://muffsy.com]: Turning off mute LED\n");
    digitalWrite(muteLed,LOW); // Turn off mute LED, no matter if it was turned on or off earlier.

    // Set mute to 1, next time toggleMute is called, it will turn ON mute
    // mute = 1 now means we're unmuted
    mute = 1; // Mute next time this function is called
  } // 
} // End toggleMute()

/*
 * Power on / off
 */
void togglePower() {

  /*
   * If powerState is 1, turn OFF: All relays OFF, power amp OFF
   */
  if (powerState == 1) {
    powerState = 2; // Setting powerState to 2 (off)

    if (mute == 1) { // If unmuted, turn on mute 
      toggleMute(); // mute variable = 1, toggleMute will turn on mute. powerState = 2, mute LED will not turn on
    } else if (mute == 0) { // If already muted, turn off mute LED
      Serial.println("[http://muffsy.com]: Mute relay stays turned ON");
      Serial.println("[http://muffsy.com]: Turning off mute LED");
      digitalWrite(muteLed,LOW); // Turning off the mute LED
    }
    
    relayOff();
    if (enableSSR == 1) { // Only turn off SSR if "enableSSR" is set to 1
      digitalWrite (SSR,LOW); // Turning off Solid State Relay
      Serial.println("[http://muffsy.com]: Solid State Relay OFF");
    }

    Serial.println("[http://muffsy.com]: Turning off power LED");
    Serial.println("[http://muffsy.com]: Power OFF\n");
    digitalWrite (LED,LOW); // Turning off the power LED
    poweronMute = 1; // Set poweronMute to 1, this will force a mute with delay on next power on

  /*
   * If powerState is 2, turn ON: Last selected relay ON, power amp (Solid State Relay ON)
   */
  } else if (powerState == 2) { // 
    powerState = 1; // Setting powerState to 1 (on)
    Serial.println("[http://muffsy.com]: Turning on power LED");
    digitalWrite (LED,HIGH); // Turning on the power lED
    previousRelay = relayCount + 1; // Trigger relayOn()
    Serial.println("[http://muffsy.com]: Power ON");

    if (enableSSR == 1) { // Only enable SSR if "enableSSR" is set to 1
      digitalWrite (SSR,HIGH); // Turning on Solid State Relay
      Serial.println("[http://muffsy.com]: Solid State Relay ON\n");
    }

    // We have just powered on
    // The circuit is muted, manually in powerOn(), toggleMute() has not been involved to set the mute variable
    // mute = 0; tells toggleMute() that we are muted, and that toggleMute() will unmute the next time it's called
    // relayOn() will call toggleMute if poweronMute = 1
    mute = 0;
    relayOn();

  } 
} // End togglePower()

/*
 * Read the rotary encoder
 */
void rotEncoder() {
  versatile_encoder->ReadEncoder();
}
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

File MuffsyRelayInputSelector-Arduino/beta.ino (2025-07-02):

/*
 * BETA-version: UNTESTED!
 * Will compile for NodeMCU-32S in Arduino IDE
 * 
 * Features:
 * - WiFi AP setup with web interface
 * - OTA updates
 * - Web-based console
 * - Clean modular code structure
 * - Persistent settings storage
 * 
 * Hardware: ESP32 NodeMCU-32S with relay board
 * 
 * Author: Enhanced version for muffsy.com
 * License: BSD 3-Clause
 */

#include <WiFi.h>
#include <WebServer.h>
#include <ArduinoOTA.h>
#include <Preferences.h>
#include <IRremote.hpp>
#include <Versatile_RotaryEncoder.h>
#include <DNSServer.h>

// ================================
// PIN DEFINITIONS
// ================================
#define RELAY_INPUT_A    16
#define RELAY_INPUT_B    12
#define RELAY_INPUT_C    27
#define RELAY_INPUT_D    33
#define RELAY_MUTE       32
#define SSR_PIN          17

#define POWER_LED        2
#define MUTE_LED         4
#define INPUT_A_LED      13
#define INPUT_B_LED      14
#define INPUT_C_LED      15
#define INPUT_D_LED      18

#define ENCODER_CLK      35
#define ENCODER_DT       34
#define ENCODER_SW       5
#define IR_RECEIVE_PIN   36

// ================================
// USER CONFIGURABLE SETTINGS
// ================================
#define FIRMWARE_VERSION "2.0.0"
#define AP_SSID          "MuffsyInputSelector"
#define AP_PASSWORD      "muffsy123"

// IR Remote codes (replace with your remote's codes)
#define IR_POWER         0x45
#define IR_MUTE          0x47
#define IR_INPUT_1       0x12
#define IR_INPUT_2       0x24
#define IR_INPUT_3       0x94
#define IR_INPUT_4       0x8
#define IR_UP            0x18
#define IR_DOWN          0x52

// Timing settings
#define STARTUP_DELAY    2000    // Mute delay on startup (ms)
#define DEBOUNCE_DELAY   200     // Button debounce (ms)
#define LONG_PRESS_TIME  1000    // Long press threshold (ms)

// ================================
// GLOBAL VARIABLES
// ================================
WebServer server(80);
DNSServer dnsServer;
Preferences prefs;
Versatile_RotaryEncoder encoder(ENCODER_CLK, ENCODER_DT, ENCODER_SW);

// Web console buffer
#define CONSOLE_BUFFER_SIZE 50
String consoleBuffer[CONSOLE_BUFFER_SIZE];
int consoleIndex = 0;
bool consoleWrapped = false;

// System state
struct SystemState {
  bool powered = false;
  bool muted = false;
  int currentInput = 1;        // 1-4
  bool ssrEnabled = false;
  String wifiSSID = "";
  String wifiPassword = "";
  bool wifiConnected = false;
  bool apMode = true;
} state;

// Timing variables
unsigned long lastIRCommand = 0;
unsigned long lastEncoderAction = 0;
bool setupComplete = false;

// ================================
// FUNCTION DECLARATIONS
// ================================
void setupHardware();
void setupWiFi();
void setupWebServer();
void setupOTA();
void setupIR();
void setupEncoder();
void loadSettings();
void saveSettings();

void handleInputSelection(int input);
void handlePowerToggle();
void handleMuteToggle();
void updateLEDs();
void updateRelays();

void processIR();
void processEncoder();
void processWebRequests();

// Console functions
void addToConsole(String message);
void serialPrintln(String message);

// Web interface handlers
void handleRoot();
void handleWiFiSetup();
void handleWiFiConnect();
void handleStatus();
void handleControl();
void handleConsole();
void handleConsoleData();
void handleOTAUpload();
void handleNotFound();

// ================================
// MAIN FUNCTIONS
// ================================
void setup() {
  Serial.begin(115200);
  delay(1000);
  
  serialPrintln("\n" + String(FIRMWARE_VERSION));
  serialPrintln("Muffsy Relay Input Selector - Enhanced");
  serialPrintln("=====================================");
  
  setupHardware();
  loadSettings();
  setupWiFi();
  setupWebServer();
  setupOTA();
  setupIR();
  setupEncoder();
  
  // Startup sequence - device starts OFF and MUTED for safety
  serialPrintln("Startup delay: " + String(STARTUP_DELAY) + "ms (safety mute period)");
  delay(STARTUP_DELAY);
  
  // Device remains off and muted until user explicitly turns it on
  // This ensures no audio signals pass through during startup
  updateLEDs();
  updateRelays();
  
  setupComplete = true;
  serialPrintln("Setup complete - ready for operation");
}

void loop() {
  if (setupComplete) {
    processIR();
    processEncoder();
    processWebRequests();
    ArduinoOTA.handle();
    
    // Handle WiFi reconnection
    if (!state.apMode && WiFi.status() != WL_CONNECTED) {
      static unsigned long lastReconnectAttempt = 0;
      if (millis() - lastReconnectAttempt > 30000) { // Try every 30 seconds
        serialPrintln("WiFi disconnected, attempting reconnection...");
        WiFi.reconnect();
        lastReconnectAttempt = millis();
      }
    }
  }
  delay(10); // Small delay to prevent watchdog issues
}

// ================================
// SETUP FUNCTIONS
// ================================
void setupHardware() {
  serialPrintln("Initializing hardware...");
  
  // Initialize relay pins
  pinMode(RELAY_INPUT_A, OUTPUT);
  pinMode(RELAY_INPUT_B, OUTPUT);
  pinMode(RELAY_INPUT_C, OUTPUT);
  pinMode(RELAY_INPUT_D, OUTPUT);
  pinMode(RELAY_MUTE, OUTPUT);
  pinMode(SSR_PIN, OUTPUT);
  
  // Initialize LED pins
  pinMode(POWER_LED, OUTPUT);
  pinMode(MUTE_LED, OUTPUT);
  pinMode(INPUT_A_LED, OUTPUT);
  pinMode(INPUT_B_LED, OUTPUT);
  pinMode(INPUT_C_LED, OUTPUT);
  pinMode(INPUT_D_LED, OUTPUT);
  
  // Set initial states - SAFETY FIRST!
  digitalWrite(RELAY_MUTE, HIGH);  // Start muted (relay OFF = muted)
  digitalWrite(SSR_PIN, LOW);      // SSR off
  
  // Turn off all input relays immediately
  digitalWrite(RELAY_INPUT_A, LOW);
  digitalWrite(RELAY_INPUT_B, LOW);
  digitalWrite(RELAY_INPUT_C, LOW);
  digitalWrite(RELAY_INPUT_D, LOW);
  
  state.muted = true;              // Always start muted
  state.powered = false;           // Start powered off for safety
  
  updateLEDs();
  serialPrintln("Hardware initialized");
}
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

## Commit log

2019-04-29 Added the IRremote.h library with fixes for ESP32
2019-04-29 Muffsy Relay Input Selector, Arduino code
    For the Muffsy Relay Input Selector 4:
    https://www.tindie.com/products/skrodahl/muffsy-relay-input-selector-kit/
2019-04-29 Added Eagle project files
    Included files: .sch, .brd, .cam, gerbers
    [relayinput4.brd, relayinput4.sch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]
2019-07-01 Update relayinput.ino
    Fixed mute.
    Was muted when it shouldn't, and vice versa.
2019-07-02 Update relayinput.ino
    Added muteLed
2019-07-04 Fixed problem with mute circuit
    Mute didn't ground the output (AMP-L/AMP-R), this version fixes that problem to make sure there's absolutely no hum while the circuit is turned off or muted.
    [relayinput4.brd, relayinput4.sch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]
2019-07-04 Eagle project files and gerbers
    Cosmetic changes to silkscreen top and bottom
    [relayinput4.brd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]
2019-07-04 Eagle project files and gerbers
    More cosmetic changes, silkscreen top
    [relayinput4.brd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]
2020-01-16 Added PlatformIO Project
    The folder /MuffsyRelayInputSelector-PlatformIO is a fully self-contained PlatformIO project for the Muffsy Relay Input Selector. No more need for manual installation of the IRremote library.
2023-07-29 Delete relayinput.ino
    Adding MuffsyRelayInputSelector-Arduino.ino instead
2023-07-29 Add files via upload
    Updated file, patched libraries no longer needed
    [MuffsyRelayInputSelector-Arduino.ino]
2023-07-29 Delete MuffsyRelayInputSelector-Arduino.ino
    Fix, file needs to be in a folder
    [MuffsyRelayInputSelector-Arduino.ino]
2023-07-29 Add files via upload
    New version of the Arduino code, patched libraries no longer needed.
    [MuffsyRelayInputSelector-Arduino.ino]
2023-07-31 Add files via upload
    Improved handling of rotary encoder, making variables volatile and atomic:
    https://forum.arduino.cc/t/esp32-crashes-when-turning-rotary-encoder-too-many-time-consecutively/1040123/2
    [MuffsyRelayInputSelector-Arduino.ino]
2023-08-03 Update MuffsyRelayInputSelector-Arduino.ino
    Added timestamp
2023-09-16 Update MuffsyRelayInputSelector-Arduino.ino
    Cleaned up code, simplification and getting rid of duplicate/unnecessary code. Much improved comments. Using Versatile_Rotaryencoder.h for the rotary encoder instead of homegrown code. Added user con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
2023-09-16 Update MuffsyRelayInputSelector-Arduino.ino
    Fixed typo
    [MuffsyRelayInputSelector-Arduino.ino]
2023-09-16 Update MuffsyRelayInputSelector-Arduino.ino
    Fixed startupDelay
    [MuffsyRelayInputSelector-Arduino.ino]
2023-09-16 Update MuffsyRelayInputSelector-Arduino.ino
    FIX: muteLED was not turned off when input selector is powered off.
    [MuffsyRelayInputSelector-Arduino.ino]
2023-09-16 Update MuffsyRelayInputSelector-Arduino.ino
    Updated instructions for startupDelay with how to disable the delay.
2023-09-16 Update MuffsyRelayInputSelector-Arduino.ino
    Added functionality for no delayed mute at power on.
2023-09-16 Update MuffsyRelayInputSelector-Arduino.ino
    FIX: Problem with rotary encoder if startupDelay set to other than 0.
    [MuffsyRelayInputSelector-Arduino.ino]
2023-09-16 Update MuffsyRelayInputSelector-Arduino.ino
    Added clarifying comment
2023-09-16 Update MuffsyRelayInputSelector-Arduino.ino
    Small comment change
2023-09-16 Update MuffsyRelayInputSelector-Arduino.ino
    Added comment to the row that loads the rotary encoder library.
2023-09-16 Update MuffsyRelayInputSelector-Arduino.ino
    Updated comment for IR rate.
2023-09-17 Update MuffsyRelayInputSelector-Arduino.ino
    Updated default IR rate from 350 ms to 125 ms, as it gives a more natural behavior.
2023-09-17 Update MuffsyRelayInputSelector-Arduino.ino
    Changed the last updated day.
2023-09-17 Update MuffsyRelayInputSelector-Arduino.ino
    No change in functionality, updated comments on the IR commands with default values.
2023-09-17 Update MuffsyRelayInputSelector-Arduino.ino
    Added a user configurable option to slow down the turn rate of the rotary encoder. Default is no delay.
2023-09-17 Update MuffsyRelayInputSelector-Arduino.ino
    Cosmetic changes
2023-09-18 Update MuffsyRelayInputSelector-Arduino.ino
    Updated comment sections
2023-09-18 Update MuffsyRelayInputSelector-Arduino.ino
    Updated comments
2023-09-18 Update MuffsyRelayInputSelector-Arduino.ino
    Typo in comments
2023-09-18 Update MuffsyRelayInputSelector-Arduino.ino
    Preparing for user configurable setting "enableSSR"
2023-09-18 Update MuffsyRelayInputSelector-Arduino.ino
    Updated comment
2023-09-19 Update MuffsyRelayInputSelector-Arduino.ino
    Finished implementing user configurable option enableSSR. It is disabled by default, as mains power is dangerous. Also added better serial monitor output for the muteLed.
2023-09-19 Update MuffsyRelayInputSelector-Arduino.ino
    Bumped change date.
2023-09-19 Update MuffsyRelayInputSelector-Arduino.ino
    BUGFIX: If mute was on, changing the channel would turn it off. Fixed smaller bugs related to togglePower and added more comments.
    [MuffsyRelayInputSelector-Arduino.ino]
2023-09-20 Update MuffsyRelayInputSelector-Arduino.ino
    Improved comments and formatting
2023-09-20 Update MuffsyRelayInputSelector-Arduino.ino
    Increased the IR Rate a smidge.
2023-09-27 Update MuffsyRelayInputSelector-Arduino.ino
    Added short delay after IR powerButton pressed, to avoid turning on immediately after power off.
    [MuffsyRelayInputSelector-Arduino.ino]
2026-05-19 autoPowerOn
    New user variable at line 62 — #define autoPowerOn 0 (set to 1 to enable), placed alongside the other startup-related defines like startupDelay and enableSSR.
    Hook into powerOn() at line 320 — after the welcome message finishes and powerState is set to 2, if autoPowerOn == 1 it calls togglePower() to power on.
    This preserves the full welcome/getting-ready flow (NVRAM read, mute relay, SSR off, startup message) and only then powers on — so the user-visible behavior is identical to a manual press, just witho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
